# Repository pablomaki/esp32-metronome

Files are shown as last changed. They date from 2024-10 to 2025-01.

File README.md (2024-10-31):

# ESP32 metronome

The inspiration for this project was mainly to learn to use freeRTOS (and RTOS in general) and the goal was to create a metronome. 

The project consists of a ESP32 microcontroller, generic rotary encoder, 128x32 OLED screen and an output device, which in my case is a relay driven with a MOSFET. The encoder is used to select the BPM and the signature mode for the metronome while the screen is used to show this information to the user. A circuit diagram/circuit design will be published as well once done.

Each of the components; encoder, output trigger and screen is handled by a separate task that is taken care of by the freeRTOS scheduler.

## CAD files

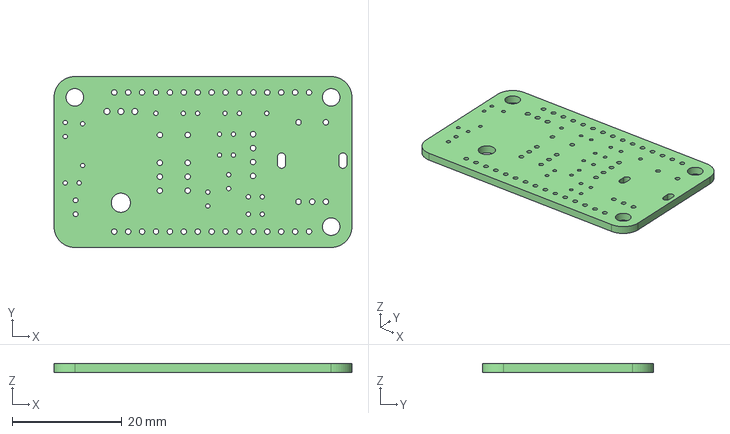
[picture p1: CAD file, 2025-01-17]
hardware/kicad/metronome_v2.step
54.4 x 31.2 x 1.60 mm

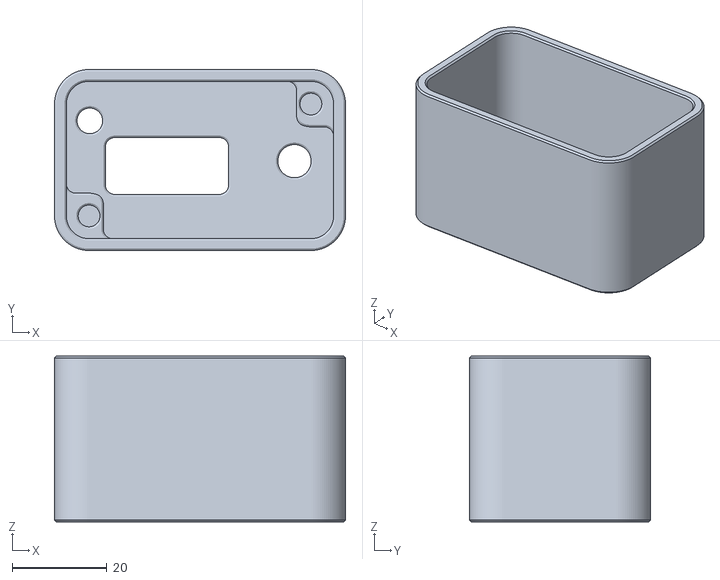
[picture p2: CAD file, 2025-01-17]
hardware/stl/metronome_top.stl
61.4 x 38.2 x 35.0

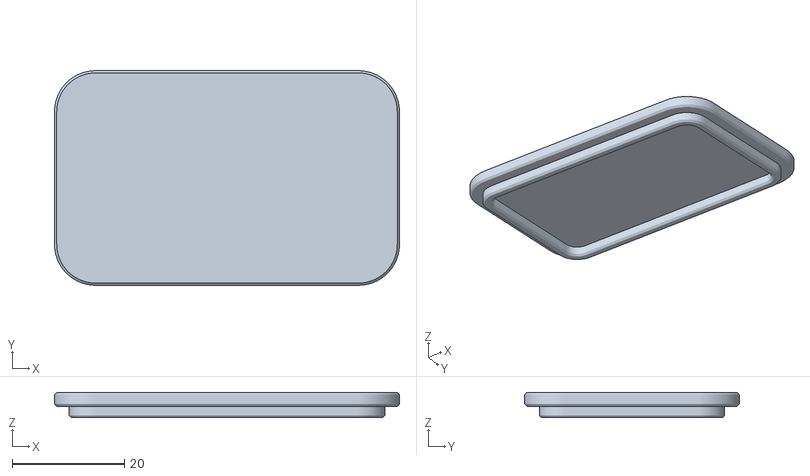
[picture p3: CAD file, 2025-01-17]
hardware/stl/metronome_bottom.stl
61.4 x 38.2 x 4.50

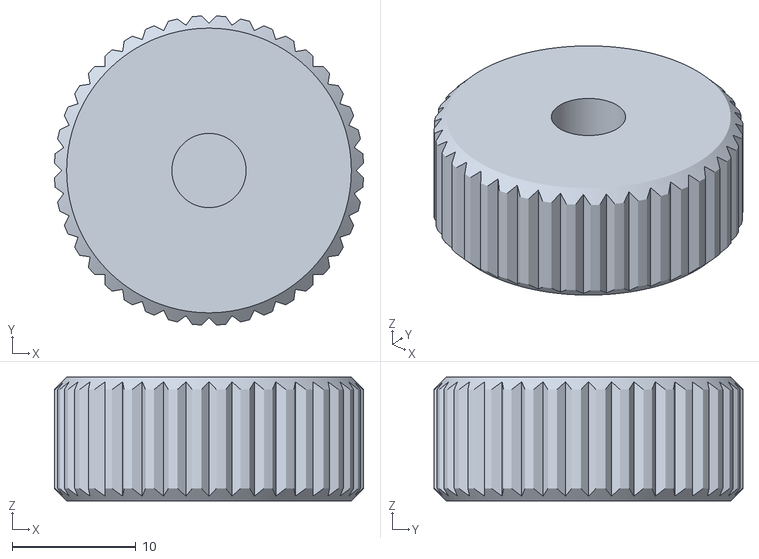
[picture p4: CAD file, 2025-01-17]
hardware/stl/metronome_nut.stl
25.0 x 25.0 x 10.0

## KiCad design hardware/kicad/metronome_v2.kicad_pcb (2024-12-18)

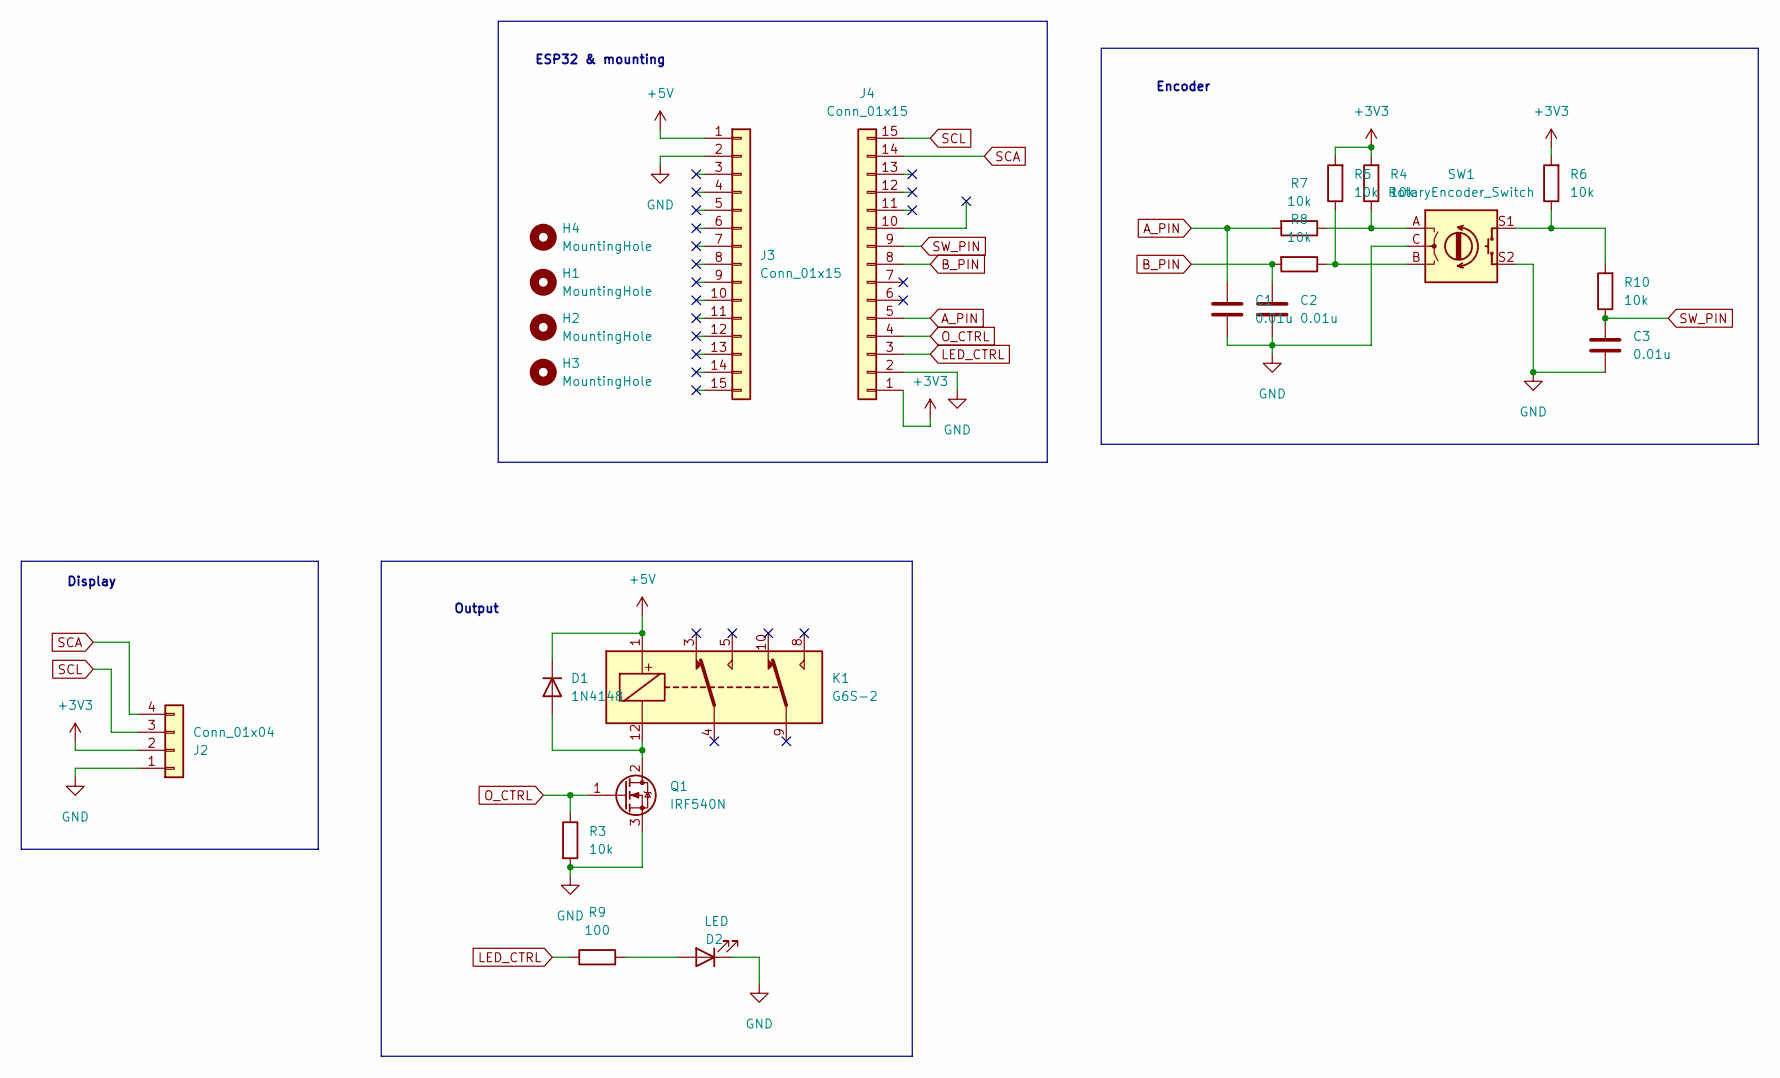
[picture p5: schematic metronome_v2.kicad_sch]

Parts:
C1, C2, C3: 0.01u; C_Disc_D5.0mm_W2.5mm_P5.00mm
D1: 1N4148; D_DO-35_SOD27_P7.62mm_Horizontal
D2: LED; LED_D3.0mm
H1, H2, H3, H4: MountingHole; MountingHole_3.2mm_M3_ISO7380
J2: Conn_01x04; PinHeader_1x04_P2.54mm_Vertical
J3, J4: Conn_01x15; PinHeader_1x15_P2.54mm_Vertical
K1: G6S-2; Relay_DPDT_Omron_G6S-2
Q1: IRF540N; TO-220-3_Horizontal_TabDown
R3, R4, R5, R6, R7, R8, R10: 10k; R_Axial_DIN0207_L6.3mm_D2.5mm_P2.54mm_Vertical
R9: 100; R_Axial_DIN0207_L6.3mm_D2.5mm_P2.54mm_Vertical
SW1: RotaryEncoder_Switch; RotaryEncoder_Alps_EC11E-Switch_Vertical_H20mm

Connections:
+3V3: J2.2, J4.1, R4.2, R5.2, R6.2
+5V: D1.1 (K), J3.1, K1.1
A_PIN: C1.1, J4.5, R7.2
B_PIN: C2.1, J4.8, R8.2
GND: C1.2, C2.2, C3.2, D2.1 (K), J2.1, J3.2, J4.2, Q1.3 (S), R3.2, SW1.C, SW1.S2
LED_CTRL: J4.3, R9.1
unnamed: D1.2 (A), K1.12, Q1.2 (D)
unnamed: D2.2 (A), R9.2
unnamed: R4.1, R7.1, SW1.A
unnamed: R5.1, R8.1, SW1.B
unnamed: R6.1, R10.2, SW1.S1
O_CTRL: J4.4, Q1.1 (G), R3.1
SCA: J2.4, J4.14
SCL: J2.3, J4.15
SW_PIN: C3.1, J4.9, R10.1

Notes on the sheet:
Display
Output
ESP32 & mounting
Encoder

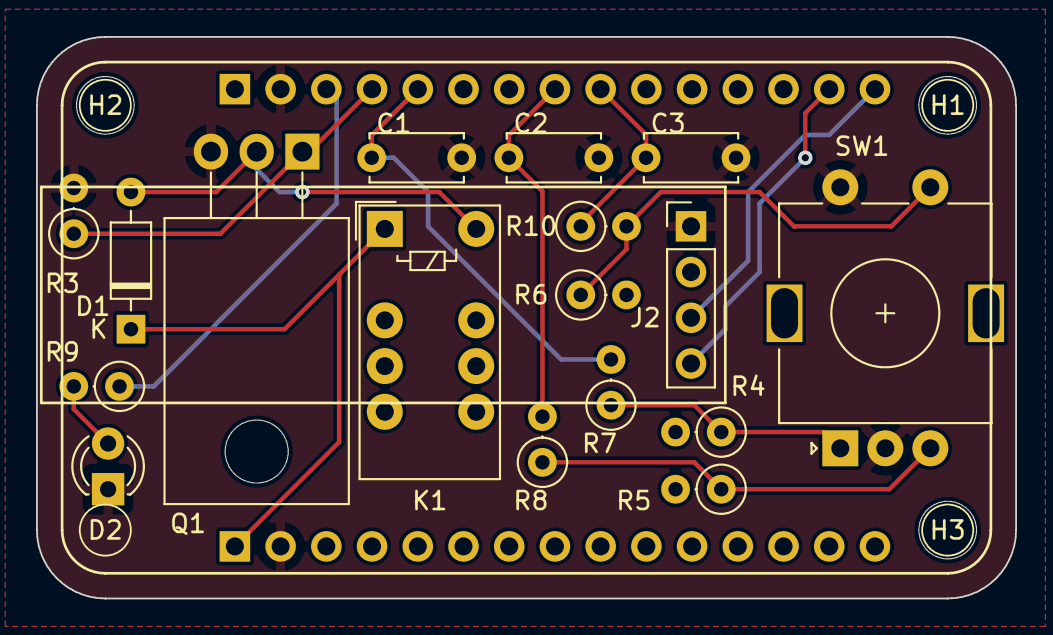
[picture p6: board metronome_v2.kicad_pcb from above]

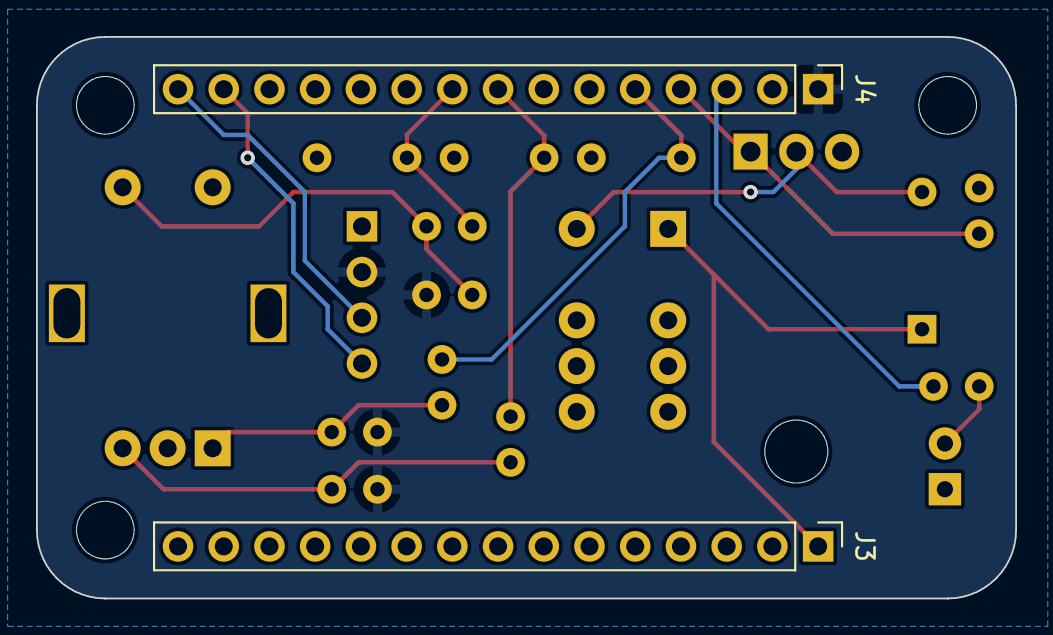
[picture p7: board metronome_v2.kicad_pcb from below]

Board: 2 copper layers, 54.4 x 31.2 mm, 22 parts (2 on the bottom side), 15 nets.

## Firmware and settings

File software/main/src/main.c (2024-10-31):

#include "encoder_handler.h"
#include "screen_handler.h"
#include "output_handler.h"
#include "shared_variables.h"

void app_main(void)
{
    // Create tag
    const char *TAG = "app_main";
    ESP_LOGI(TAG, "App main started.");

    // Return value for handling errors from  the called functions
    esp_err_t ret;

    // Initialize semaphores for handling the shared variables
    ret = init_semaphores();
    if (ret != ESP_OK)
    {
        ESP_LOGE(TAG, "Failed to initialize semaphores: %s", esp_err_to_name(ret));
        esp_restart();
    }

    // Setup and start the encoder handler
    start_encoder_handler();
    if (ret != ESP_OK)
    {
        ESP_LOGE(TAG, "Failed to start the encoder handler: %s", esp_err_to_name(ret));
        esp_restart();
    }

    // Setup and start the screen handler
    start_screen_handler();
    if (ret != ESP_OK)
    {
        ESP_LOGE(TAG, "Failed to start the screen handler: %s", esp_err_to_name(ret));
        esp_restart();
    }

    // Setup and start the output handler
    start_output_handler();
    if (ret != ESP_OK)
    {
        ESP_LOGE(TAG, "Failed to start the output handler: %s", esp_err_to_name(ret));
        esp_restart();
    }
}

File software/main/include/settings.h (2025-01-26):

#ifndef SETTINGS_H
#define SETTINGS_H

// ******* PINSETUP *******
// ENCODER
#define ENC_A_PIN 4
#define ENC_B_PIN 5
#define ENC_SW_PIN 18
// SCREEN
#define SSD1306_SDA_PIN 22
#define SSD1306_SCL_PIN 23
#define SSD1306_RST_PIN -1
// OUTPUT
#define OUTPUT_PIN 2
#define LED_PIN 15

// ******* OTHER SETTINGS *******
// OUTPUT
#define OUTPUT_ACTIVATION_DURATION 50 // milliseconds
#define BPM_START 80                  // BPM to start with
#define SIGNATURE_START 0             // index
#define INVERT_SCREEN 1               // 0 for non inverted, 1 to invert

// INPUT
#define FAST_CHANGE_MULTIPLIER 5
#define DOUBLE_CLICK_US 5E5       // microseconds
#define FAST_CHANGE_US 1E5        // microseconds
#define FAST_CHANGE_EXPIRE_US 1E6 // microseconds
#define ENC_A_DEBOUNCE 1000       // microseconds
#define ENC_B_DEBOUNCE 1000       // microseconds
#define ENC_SW_DEBOUNCE 200000    // microseconds
#define ENC_SW_LONGPRESS 1000000  // microseconds

#endif // SETTINGS_H

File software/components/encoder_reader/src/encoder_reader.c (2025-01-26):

#include "../include/encoder_reader.h"

SemaphoreHandle_t semaphore;
static void IRAM_ATTR pin_a_isr_handler(void *arg)
{
    encoder_reader_handle_t encoder_handle = (encoder_reader_handle_t)arg;
    if (xSemaphoreTakeFromISR(semaphore, NULL) == pdTRUE)
    {
        if (!esp_timer_is_active(encoder_handle->pin_a_timer))
        {
            ESP_ERROR_CHECK(esp_timer_start_once(encoder_handle->pin_a_timer, encoder_handle->a_debounce_us));
        }
        else
        {
            ESP_ERROR_CHECK(esp_timer_restart(encoder_handle->pin_a_timer, encoder_handle->a_debounce_us));
        }
        xSemaphoreGiveFromISR(semaphore, NULL); // Release the semaphore
    }
}

static void IRAM_ATTR pin_b_isr_handler(void *arg)
{
    encoder_reader_handle_t encoder_handle = (encoder_reader_handle_t)arg;
    if (xSemaphoreTakeFromISR(semaphore, NULL) == pdTRUE)
    {
        encoder_handle->pin_b_current_value = gpio_get_level(encoder_handle->pin_b);
        if (!esp_timer_is_active(encoder_handle->pin_b_timer))
        {
            ESP_ERROR_CHECK(esp_timer_start_once(encoder_handle->pin_b_timer, encoder_handle->b_debounce_us));
        }
        else
        {
            ESP_ERROR_CHECK(esp_timer_restart(encoder_handle->pin_b_timer, encoder_handle->b_debounce_us));
        }
        xSemaphoreGiveFromISR(semaphore, NULL); // Release the semaphore
    }
}

static void IRAM_ATTR pin_sw_isr_handler(void *arg)
{
    encoder_reader_handle_t encoder_handle = (encoder_reader_handle_t)arg;
    if (xSemaphoreTakeFromISR(semaphore, NULL) == pdTRUE)
    {
        bool neg_edge = gpio_get_level(encoder_handle->pin_sw) ? false : true;
        if (neg_edge)
        {
            // Handle long press timer
            if (!esp_timer_is_active(encoder_handle->pin_sw_longpress_timer))
            {
                ESP_ERROR_CHECK(esp_timer_start_once(encoder_handle->pin_sw_longpress_timer, encoder_handle->sw_longpress_us));
            }
            else
            {
                ESP_ERROR_CHECK(esp_timer_restart(encoder_handle->pin_sw_longpress_timer, encoder_handle->sw_longpress_us));
            }
        }
        else
        {
            // Stop long press timer            
            if (esp_timer_is_active(encoder_handle->pin_sw_longpress_timer))
            {
                ESP_ERROR_CHECK(esp_timer_stop(encoder_handle->pin_sw_longpress_timer));
            }
            // Handle debounce timer
            if (!esp_timer_is_active(encoder_handle->pin_sw_timer))
            {
                ESP_ERROR_CHECK(esp_timer_start_once(encoder_handle->pin_sw_timer, encoder_handle->sw_debounce_us));
            }
            else
            {
                ESP_ERROR_CHECK(esp_timer_restart(encoder_handle->pin_sw_timer, encoder_handle->sw_debounce_us));
            }
        }
        xSemaphoreGiveFromISR(semaphore, NULL); // Release the semaphore
    }
}

static void pin_a_debounce_cb(void *arg)
{
    encoder_reader_handle_t encoder_handle = (encoder_reader_handle_t)arg;
    if (xSemaphoreTakeFromISR(semaphore, NULL) == pdTRUE)
    {
        if (gpio_get_level(encoder_handle->pin_a) == 0)
        {
            encoder_tick_t encoder_tick = {
                .direction = (encoder_handle->pin_b_value == 1) ? 1 : -1,
                .time = esp_timer_get_time()};
            xQueueSendFromISR(encoder_handle->tick_queue, &encoder_tick, NULL);
        }
        xSemaphoreGiveFromISR(semaphore, NULL); // Release the semaphore
    }
}

static void pin_b_debounce_cb(void *arg)
{
    encoder_reader_handle_t encoder_handle = (encoder_reader_handle_t)arg;
    if (xSemaphoreTakeFromISR(semaphore, NULL) == pdTRUE)
    {
        encoder_handle->pin_b_value = encoder_handle->pin_b_current_value;
        xSemaphoreGiveFromISR(semaphore, NULL); // Release the semaphore
    }
}

static void pin_sw_debounce_cb(void *arg)
{
    encoder_reader_handle_t encoder_handle = (encoder_reader_handle_t)arg;
    if (xSemaphoreTakeFromISR(semaphore, NULL) == pdTRUE)
    {
        encoder_tick_t encoder_tick = {
            .direction = 0,
            .time = esp_timer_get_time()};
        xQueueSendFromISR(encoder_handle->tick_queue, &encoder_tick, NULL);
        xSemaphoreGiveFromISR(semaphore, NULL); // Release the semaphore
    }
}

static void pin_sw_longpress_cb(void *arg)
{
    encoder_reader_handle_t encoder_handle = (encoder_reader_handle_t)arg;
    if (xSemaphoreTakeFromISR(semaphore, NULL) == pdTRUE)
    {
        encoder_tick_t encoder_tick = {
            .direction = 10,
            .time = esp_timer_get_time()};
        xQueueSendFromISR(encoder_handle->tick_queue, &encoder_tick, NULL);
        xSemaphoreGiveFromISR(semaphore, NULL); // Release the semaphore
    }
}

esp_err_t encoder_reader_setup(const encoreder_reader_settings_t *args,
                               encoder_reader_handle_t *out_handle)
{
    // Check input arguments
    if (args == NULL || out_handle == NULL || args->pin_a == 0 ||
        args->pin_b == 0 || args->pin_sw == 0 || args->a_debounce_us == 0 ||
        args->b_debounce_us == 0 || args->sw_debounce_us == 0 || args->sw_longpress_us == 0 || args->tick_queue == NULL)
    {
        return ESP_ERR_INVALID_ARG;
    }

    // Allocate memory
    encoder_reader_handle_t result = (encoder_reader_handle_t)heap_caps_calloc(1, sizeof(*result), MALLOC_CAP_8BIT | MALLOC_CAP_INTERNAL);
    if (result == NULL)
    {
        return ESP_ERR_NO_MEM;
    }

    // Fill the created handle and return
    result->pin_a = args->pin_a;
    result->pin_b = args->pin_b;
    result->pin_sw = args->pin_sw;
    result->a_debounce_us = args->a_debounce_us;
    result->b_debounce_us = args->b_debounce_us;
    result->sw_debounce_us = args->sw_debounce_us;
    result->sw_longpress_us = args->sw_longpress_us;
    result->tick_queue = args->tick_queue;
    *out_handle = result;

    // Create the semaphore
    semaphore = xSemaphoreCreateBinary();
    if (semaphore == NULL)
    {
        // Handle semaphore creation failure
        return ESP_ERR_NO_MEM;
    }

    // Initialize the semaphore to available state
    xSemaphoreGive(semaphore);

    return ESP_OK;
}
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

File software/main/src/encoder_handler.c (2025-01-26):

#include "encoder_handler.h"
#include "shared_variables.h"
#include "esp_sleep.h"

action_t action_select = {0, 0, 0};
action_t action_up = {0, 0, 1};
action_t action_down = {0, 0, -1};

void handle_sleep_mode(encoder_reader_handle_t encoder)
{
    // Enter sleep mode with SW pin as the wakeup
    static const char *TAG = "encoder_handler_task";
    ESP_LOGI(TAG, "Sleep mode requested, handling request");

    // Turn off the screen, LED and output device. Wait for the action to take effect
    switch_system_off();
    vTaskDelay(pdMS_TO_TICKS(100));

    // Disable existing interrupt
    encoder_reader_disable(encoder);

    // Enable ENC_SW_PIN as sleep wakeup pin
    gpio_wakeup_enable(ENC_SW_PIN, GPIO_INTR_LOW_LEVEL);
    esp_sleep_enable_gpio_wakeup();
    ESP_LOGI(TAG, "Waiting for GPIO%d to go high.", ENC_SW_PIN);
    while (gpio_get_level(ENC_SW_PIN) == 0) {
        vTaskDelay(pdMS_TO_TICKS(10));
    }

    // Enter sleep mode
    ESP_LOGI(TAG, "Entring sleep mode... Wake up configured to GPIO%d", ENC_SW_PIN);
    vTaskDelay(pdMS_TO_TICKS(100));
    esp_light_sleep_start();

    // Exit sleep mode. Wait for a bit before switching the system on to avoid unnecessary GPIO callbacks
    ESP_LOGI(TAG, "Exiting sleep mode, enabling interrput back for GPIO%d pin.", ENC_SW_PIN);
    vTaskDelay(pdMS_TO_TICKS(1000));
    switch_system_on();
    encoder_reader_enable(encoder);
}

void handle_select(int8_t prev_direction, encoder_tick_t *tick)
{
    static const char *TAG = "encoder_handler_task";

    // Nullify up and down button counters
    action_up.consecutive_ticks = 0;
    action_down.consecutive_ticks = 0;

    // In case the selected_bpm differs from the candidate bpm, change bpm to the selected one
    if (get_selected_bpm() != get_candidate_bpm())
    {
        ESP_LOGI(TAG, "Changing the bpm to %d", get_candidate_bpm());
        select_bpm();
    }
    // In case the selected bpm is the same as the candidate bpm, change the signature mode
    else
    {
        ESP_LOGI(TAG, "Changing the signature mode");
        change_signature_mode();
    }

    // // In case of doubleclick, change signature mode and reset double click counter
    // if (tick->time - action_select.prev_tick_time < DOUBLE_CLICK_US && tick->direction == prev_direction && action_select.consecutive_ticks > 0)
    // {
    //     ESP_LOGI(TAG, "Changing the signature mode");
    //     change_signature_mode();
    //     action_select.consecutive_ticks = 0;
    // }
    // // In case of single click, select the bpm
    // else
    // {
    //     // Select the current bpm
    //     ESP_LOGI(TAG, "Changing the bpm to %d", get_candidate_bpm());
    //     select_bpm();

    //     // Update select button info and set direction as previous direction
    //     action_select.consecutive_ticks++;
    //     action_select.prev_tick_time = tick->time;
    // }
}

int8_t handle_up_down(int8_t prev_direction, encoder_tick_t *tick, action_t *action)
{
    // Nullify up and select button counters
    action_select.consecutive_ticks = 0;
    if (action->direction == 1)
    {
        action_down.consecutive_ticks = 0;
    }
    else
    {
        action_up.consecutive_ticks = 0;
    }

    // Count towards fast changes if time between last tick is below the set limit and direction is the same
    // In case direction is different or time since last change is over 1 second, zero the count
    uint64_t time_since_last_tick = tick->time - action->prev_tick_time;
    if (time_since_last_tick < FAST_CHANGE_US && tick->direction == prev_direction)
    {
        action->consecutive_ticks++;
    }
    // In case direction is different or time since last change is over the set limit, zero the count
    else if (time_since_last_tick > FAST_CHANGE_EXPIRE_US || tick->direction != prev_direction)
    {
        action->consecutive_ticks = 1;
    }
    // Update select button info
    action->prev_tick_time = tick->time;

    // With 3 or more fast changes, multiply change by the set value
    return action->consecutive_ticks > 3 ? tick->direction * FAST_CHANGE_MULTIPLIER : tick->direction;
}

void encoder_handler_task(void *arg)
{
    // Create tag
    static const char *TAG = "encoder_handler_task";
    ESP_LOGI(TAG, "Encoder handler task initiated.");

    // Unpack the necessary parameters
    void** args = (void**)arg;
    encoder_reader_handle_t encoder = (encoder_reader_handle_t)args[0];
    QueueHandle_t encoder_tick_queue = (QueueHandle_t)args[1];

    // Define necessary parameters
    encoder_tick_t tick;
    int8_t prev_direction = 0;

    // Loop for receiving ticks from the queue
    while (true)
    {
        if (xQueueReceive(encoder_tick_queue, &tick, pdMS_TO_TICKS(5000)))
        {
            // Handle bpm set command
            if (tick.direction == 0)
            {
                handle_select(prev_direction, &tick);
                prev_direction = tick.direction;
                continue;
            }
            else if (tick.direction == 10)
            {
                handle_sleep_mode(encoder);
            }
            // Handle down click and get multiplier for changing the bpm value
            else if (tick.direction == -1)
            {
                int8_t bpm_delta = handle_up_down(prev_direction, &tick, &action_down);
                prev_direction = tick.direction;
                change_bpm(bpm_delta);
            }
            // Handle up click and get multiplier for changing the bpm value
            else if (tick.direction == 1)
            {
                int8_t bpm_delta = handle_up_down(prev_direction, &tick, &action_up);
                prev_direction = tick.direction;
                change_bpm(bpm_delta);
            }
            else
            {
                ESP_LOGW(TAG, "Unknown tick direction: %d", tick.direction);
                prev_direction = tick.direction;
            }
        }
        // Revert any change in BPM not selected with unconfirmed changes and no action for too long
        else if (!bpm_selcted())
        {
            reset_candidate_bpm();
            ESP_LOGI(TAG, "BPM change not confirmed in time, reverting.");
        }
    }
}
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

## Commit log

2024-12-18 Add pin to flash led at the beginning of a bar
2024-12-18 Change encoder functionality to fit how it should work on the PCB
2024-12-18 Add HW design to repository and arrange repository better
    [metronome_v2.kicad_pcb, metronome_v2.kicad_sch]
2025-01-17 Arrange hardware folder
    [metronome_bottom.stl, metronome_nut.stl, metronome_top.stl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]
2025-01-26 Fix typo in encoder_reader CMakeLists.txt file
2025-01-26 Fallback latest changes for output, add long press for SW_PIN which puts the device to sleep, add handling for sleep mode
